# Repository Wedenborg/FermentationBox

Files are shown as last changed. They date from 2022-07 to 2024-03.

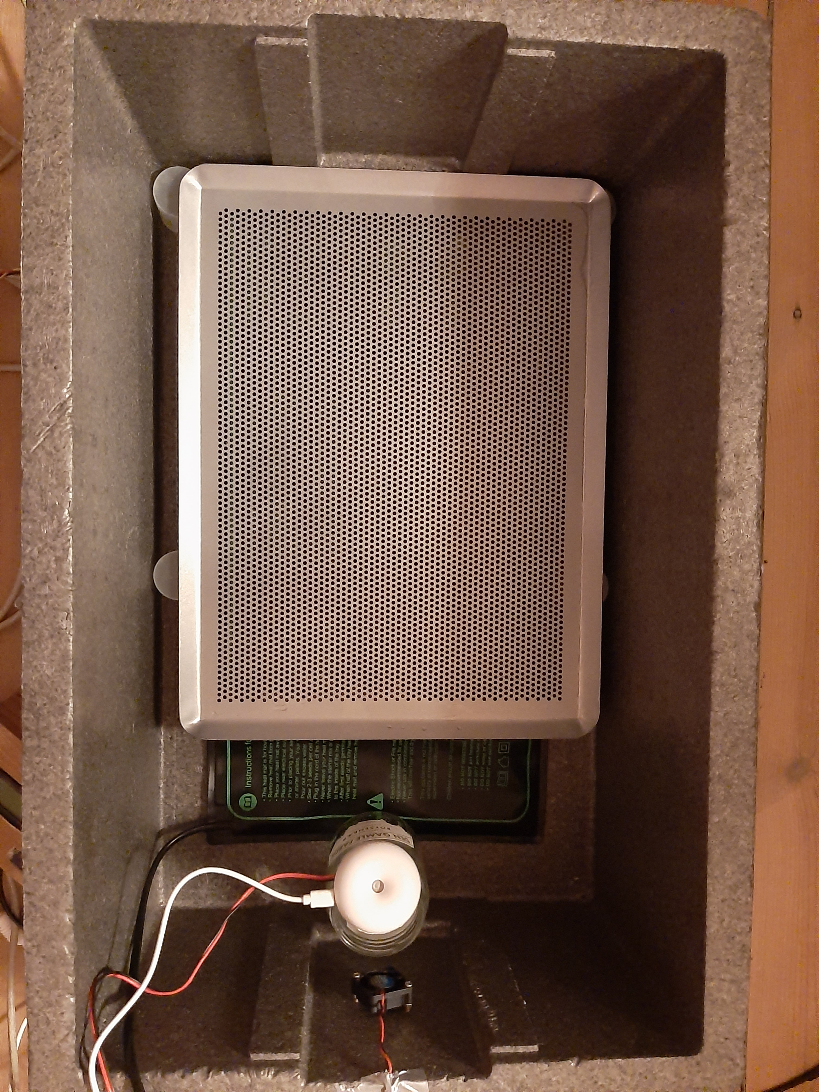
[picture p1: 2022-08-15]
photos/20220815_225923.jpg

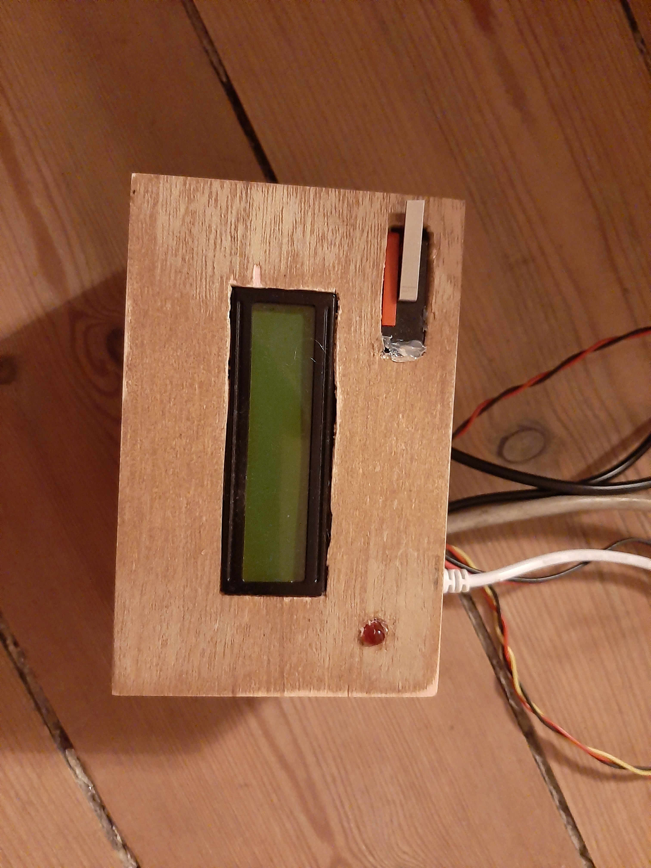
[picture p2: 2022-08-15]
photos/20220815_230012.jpg

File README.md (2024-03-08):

# Fermentation Box
Fermentation box inspired by Noma Guide to Fermentation. 

### Materials:

* 1 insulated box (approx. 60x39x24 cm)
* 1 Raspberry pi 3b+ 
* 1 Raspberry pi power supply
* 1 DHT11 sensor 
* 1 4 relay module (2PH63083A)
* 1 Heating mat 
* 1 Humidifier
* 1 LCD display
* 2 fans, one for the fermentation box and one for cooling hardware box
* 1 USB B to USB micro cable (approx. 2m)
* Wires 
* perforated baking tray (approx. 40x30 cm)
* 4 stands to lift the baking tray off the heating mat

### To be implemented: 

* More efficient control system -> It would be cool with a kalmanfilter or something! 

### Known issues that I do not know how to solve: 
* The humidifier turns on and off with a pulse signal. Sometimes something failes during start up, such that the humidifier is out of sync. \n I think I should replace the humidifier with one that has a real on/off switch and not just a pulse. 

### Modify rc.local to run on start up: 

1. On the Pi edit the rc.local file, which can be accessed using the following command: 

``` sudo nano /etc/rc.local ```

2. Add the file to be executed at the bottom of the page, but before the ```exit 0``` command. Here & is added at the end of the filename, as the script runs continously. 

```python3 /home/pi/FermentationBox/main.py &```

3. Make sure file is executeable. 

```sudo chmod +x /etc/rc.local```

4. Reboot system. 

```sudo reboot```

Now the program should start. 

### Setup:
fritzing file also available. 
Be aware of the gpio pins. The numbering varies between the code and the fritzing sketch.

![alt text](https://github.com/Wedenborg/FermentationBox/blob/main/preliminaryTestSetup.png)

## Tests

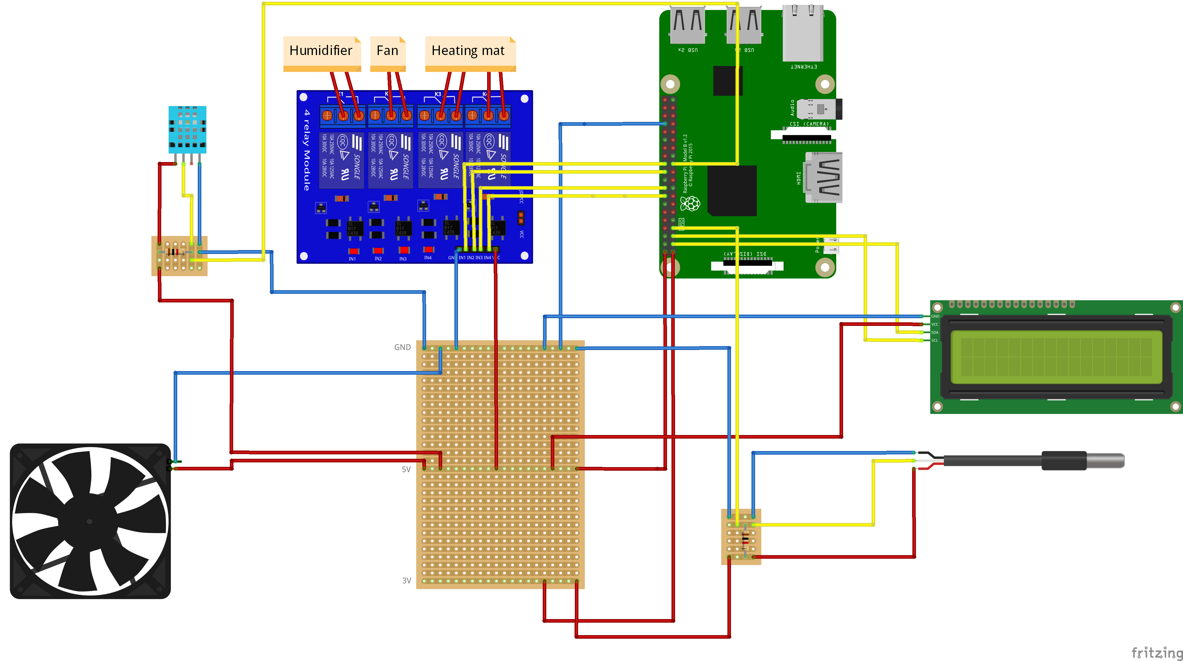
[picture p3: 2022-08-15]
preliminaryTestSetup.png

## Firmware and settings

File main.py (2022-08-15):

import os
import glob
import numpy as np
import Adafruit_DHT
import RPi.GPIO as GPIO
from datetime import datetime
# Import sleep Module for timing
from time import sleep
import csv

import i2c_lcd_driver 
import temperature_sensor_code as stickTemp

import mysql.connector as msql
from mysql.connector import Error

os.system('modprobe w1-gpio')
os.system('modprobe w1-therm')
base_dir = '/sys/bus/w1/devices/'
device_folder = glob.glob(base_dir + '28*')[0]
device_file = device_folder + '/w1_slave'


# Define pins
BlaaTemp = 22 
BrunTemp = 23
Sensor = 25
Humid = 27
Fan = 24
knap = 5
led = 6

mylcd = i2c_lcd_driver.lcd()
GPIO.setmode(GPIO.BCM)
GPIO.setwarnings(False)
GPIO.setup(BlaaTemp, GPIO.OUT) # GPIO Assign mode
GPIO.setup(BrunTemp, GPIO.OUT) # GPIO Assign mode
GPIO.setup(Humid, GPIO.OUT) # GPIO Assign mode
GPIO.setup(Sensor, GPIO.OUT) # GPIO Assign mode
GPIO.setup(Fan, GPIO.OUT) # GPIO Assign mode
GPIO.setup(led, GPIO.OUT) # GPIO Assign mode
GPIO.setup(knap, GPIO.IN) # GPIO Assign mode


 
def heatmatON(temp1,temp2):
    # Function that turns on heating mat
    GPIO.output(temp1, GPIO.LOW)
    GPIO.output(temp2, GPIO.LOW)

    return

def heatmatOFF(temp1,temp2):
    # Function that turns off heating mat
    GPIO.output(temp1, GPIO.HIGH)
    GPIO.output(temp2, GPIO.HIGH)

    return

def signalHumidifier(Humid):
    # Function that turns the humidifier on or off
    GPIO.output(Humid, GPIO.LOW)
    sleep(1)
    GPIO.output(Humid, GPIO.HIGH)
    return

def writeToDB(path,p):
    dbData =open(path,'r+')
    conn = msql.connect(host=p[0], user=p[1],  
            password=p[2]) #give ur username, password
    try:
        for row in dbData:
            t = row.strip('\n').split(',')
            cursor = conn.cursor()
            cursor.execute("use bnew_dk_db;")
            sql = 'INSERT INTO bnew_dk_db.kojiTable VALUES (%s,%s,%s,%s,%s);'
            cursor.execute(sql,t)
            # the connection is not auto committed by default, so we must commit to save our changes
            conn.commit()
    except Error as e:
        mylcd.lcd_display_string("Error while connecting to MySQL",1)
        mylcd.lcd_display_string(e,2)
    else:
        fileVariable = open(path, 'r+')
        temp = fileVariable.truncate(0)
        fileVariable.close()
    finally:
        dbData.close()
    return
    

def storeData(tempS, temperature, humidity, path):
    line = str(tempS) + "," + str(temperature) + "," + str(humidity) + "," + datetime.now().strftime('%Y-%m-%d %H:%M:%S') + "," + str(humidifier)
    out=open(path,"a")
    t = out.write(line+'\n')
    out.close()
    return

p = np.loadtxt("/home/emilie/Desktop/Code/FermentationBox/db.txt", delimiter=",", dtype=str)
path = '/home/emilie/Desktop/Code/FermentationBox/test.txt'


time = datetime.now()
timeOld = time
lastStored = time
humidifier = 0
GPIO.output(Fan, GPIO.LOW) # Turn on fan for better air circulation
heatmatOFF(BlaaTemp,BrunTemp)
mylcd.lcd_display_string("Starting...",1,0)
KorHumid = 1
f = 20
GPIO.output(led,GPIO.LOW) 
while True:
    time = datetime.now()
    
    knapInd = GPIO.input(knap)
    if (knapInd == 1):
        if (KorHumid == 1):
            KorHumid = 0
            GPIO.output(led,GPIO.HIGH)
            if (humidifier == 1):
                humidifier = 0
                signalHumidifier(Humid)
            sleep(3)
        else:
            KorHumid = 1
            GPIO.output(led,GPIO.LOW)
    
        
    tempS = stickTemp.read_temp()
    humidity, temperature = Adafruit_DHT.read_retry(11, Sensor)
    if humidity is not None and temperature is not None:
        mylcd.lcd_clear()
        mylcd.lcd_display_string("Temperature: "+str(tempS),1,0)
        mylcd.lcd_display_string("Humidity: "+str(humidity),2,0)
        mylcd.lcd_display_string(str(knapInd),2,15)

    if abs((time-lastStored).total_seconds()) >= 60:
        storeData(tempS, temperature, humidity,path)
        lastStored = datetime.now()
            
            
    if tempS < 28:
        heatmatON(BlaaTemp,BrunTemp)
    elif tempS > 34:
        heatmatOFF(BlaaTemp,BrunTemp)
            
            
    if humidity < 70 and KorHumid == 1 and humidifier == 0:
        if abs((time-timeOld).total_seconds()) >= 120:
            signalHumidifier(Humid)
            humidifier = 1
            timeOld = time

            if humidity <60:
                f = 40
            else: 
                f = 20

    if KorHumid == 1 and humidifier == 1 and abs((time-timeOld).total_seconds()) >= f:
        signalHumidifier(Humid)
        humidifier = 0
        timeOld = time

    if datetime.now().strftime('%H:%M') == '00:00':
        writeToDB(path,p)

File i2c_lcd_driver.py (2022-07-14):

# -*- coding: utf-8 -*-
# Original code found at:
# https://gist.github.com/DenisFromHR/cc863375a6e19dce359d

"""
Compiled, mashed and generally mutilated 2014-2015 by Denis Pleic
Made available under GNU GENERAL PUBLIC LICENSE

# Modified Python I2C library for Raspberry Pi
# as found on http://www.recantha.co.uk/blog/?p=4849
# Joined existing 'i2c_lib.py' and 'lcddriver.py' into a single library
# added bits and pieces from various sources
# By DenisFromHR (Denis Pleic)
# 2015-02-10, ver 0.1

"""

# i2c bus (0 -- original Pi, 1 -- Rev 2 Pi)
I2CBUS = 1

# LCD Address
ADDRESS = 0x27

import smbus
from time import sleep

class i2c_device:
   def __init__(self, addr, port=I2CBUS):
      self.addr = addr
      self.bus = smbus.SMBus(port)

# Write a single command
   def write_cmd(self, cmd):
      self.bus.write_byte(self.addr, cmd)
      sleep(0.0001)

# Write a command and argument
   def write_cmd_arg(self, cmd, data):
      self.bus.write_byte_data(self.addr, cmd, data)
      sleep(0.0001)

# Write a block of data
   def write_block_data(self, cmd, data):
      self.bus.write_block_data(self.addr, cmd, data)
      sleep(0.0001)

# Read a single byte
   def read(self):
      return self.bus.read_byte(self.addr)

# Read
   def read_data(self, cmd):
      return self.bus.read_byte_data(self.addr, cmd)

# Read a block of data
   def read_block_data(self, cmd):
      return self.bus.read_block_data(self.addr, cmd)


# commands
LCD_CLEARDISPLAY = 0x01
LCD_RETURNHOME = 0x02
LCD_ENTRYMODESET = 0x04
LCD_DISPLAYCONTROL = 0x08
LCD_CURSORSHIFT = 0x10
LCD_FUNCTIONSET = 0x20
LCD_SETCGRAMADDR = 0x40
LCD_SETDDRAMADDR = 0x80

# flags for display entry mode
LCD_ENTRYRIGHT = 0x00
LCD_ENTRYLEFT = 0x02
LCD_ENTRYSHIFTINCREMENT = 0x01
LCD_ENTRYSHIFTDECREMENT = 0x00

# flags for display on/off control
LCD_DISPLAYON = 0x04
LCD_DISPLAYOFF = 0x00
LCD_CURSORON = 0x02
LCD_CURSOROFF = 0x00
LCD_BLINKON = 0x01
LCD_BLINKOFF = 0x00

# flags for display/cursor shift
LCD_DISPLAYMOVE = 0x08
LCD_CURSORMOVE = 0x00
LCD_MOVERIGHT = 0x04
LCD_MOVELEFT = 0x00

# flags for function set
LCD_8BITMODE = 0x10
LCD_4BITMODE = 0x00
LCD_2LINE = 0x08
LCD_1LINE = 0x00
LCD_5x10DOTS = 0x04
LCD_5x8DOTS = 0x00

# flags for backlight control
LCD_BACKLIGHT = 0x08
LCD_NOBACKLIGHT = 0x00

En = 0b00000100 # Enable bit
Rw = 0b00000010 # Read/Write bit
Rs = 0b00000001 # Register select bit

class lcd:
   #initializes objects and lcd
   def __init__(self):
      self.lcd_device = i2c_device(ADDRESS)

      self.lcd_write(0x03)
      self.lcd_write(0x03)
      self.lcd_write(0x03)
      self.lcd_write(0x02)

      self.lcd_write(LCD_FUNCTIONSET | LCD_2LINE | LCD_5x8DOTS | LCD_4BITMODE)
      self.lcd_write(LCD_DISPLAYCONTROL | LCD_DISPLAYON)
      self.lcd_write(LCD_CLEARDISPLAY)
      self.lcd_write(LCD_ENTRYMODESET | LCD_ENTRYLEFT)
      sleep(0.2)


   # clocks EN to latch command
   def lcd_strobe(self, data):
      self.lcd_device.write_cmd(data | En | LCD_BACKLIGHT)
      sleep(.0005)
      self.lcd_device.write_cmd(((data & ~En) | LCD_BACKLIGHT))
      sleep(.0001)

   def lcd_write_four_bits(self, data):
      self.lcd_device.write_cmd(data | LCD_BACKLIGHT)
      self.lcd_strobe(data)

   # write a command to lcd
   def lcd_write(self, cmd, mode=0):
      self.lcd_write_four_bits(mode | (cmd & 0xF0))
      self.lcd_write_four_bits(mode | ((cmd << 4) & 0xF0))

   # write a character to lcd (or character rom) 0x09: backlight | RS=DR<
   # works!
   def lcd_write_char(self, charvalue, mode=1):
      self.lcd_write_four_bits(mode | (charvalue & 0xF0))
      self.lcd_write_four_bits(mode | ((charvalue << 4) & 0xF0))
  
   # put string function with optional char positioning
   def lcd_display_string(self, string, line=1, pos=0):
    if line == 1:
      pos_new = pos
    elif line == 2:
      pos_new = 0x40 + pos
    elif line == 3:
      pos_new = 0x14 + pos
    elif line == 4:
      pos_new = 0x54 + pos

    self.lcd_write(0x80 + pos_new)

    for char in string:
      self.lcd_write(ord(char), Rs)

   # clear lcd and set to home
   def lcd_clear(self):
      self.lcd_write(LCD_CLEARDISPLAY)
      self.lcd_write(LCD_RETURNHOME)

   # define backlight on/off (lcd.backlight(1); off= lcd.backlight(0)
   def backlight(self, state): # for state, 1 = on, 0 = off
      if state == 1:
         self.lcd_device.write_cmd(LCD_BACKLIGHT)
      elif state == 0:
         self.lcd_device.write_cmd(LCD_NOBACKLIGHT)

   # add custom characters (0 - 7)
   def lcd_load_custom_chars(self, fontdata):
      self.lcd_write(0x40);
      for char in fontdata:
         for line in char:
            self.lcd_write_char(line)      

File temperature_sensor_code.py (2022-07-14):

"""
Code from https://github.com/pimylifeup/temperature_sensor/blob/master/temperature_sensor_code.py
"""

import os
import glob
import time
 
os.system('modprobe w1-gpio')
os.system('modprobe w1-therm')
 
base_dir = '/sys/bus/w1/devices/'
device_folder = glob.glob(base_dir + '28*')[0]
device_file = device_folder + '/w1_slave'
 
def read_temp_raw():
    f = open(device_file, 'r')
    lines = f.readlines()
    f.close()
    return lines
 
def read_temp():
    lines = read_temp_raw()
    while lines[0].strip()[-3:] != 'YES':
        time.sleep(0.2)
        lines = read_temp_raw()
    equals_pos = lines[1].find('t=')
    if equals_pos != -1:
        temp_string = lines[1][equals_pos+2:]
        temp_c = float(temp_string) / 1000.0
        return temp_c
	

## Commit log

2022-06-14 [Script up and running]
    [test.csv]
2022-06-14 [Updates to readme and added except keyboard interrupt to main]
2022-06-15 [Error corrected in humidifier function]
    [main.py]
2022-07-14 [system extended with fan, LCD display and temperature probe]
    [test.csv]
2022-07-14 [code w. ref for display and probe]
    [test.csv]
2022-07-14 [problems with display on start up]
    [test.csv]
2022-07-16 [Program edited to use current time instead of sleep]
    [test.csv]
2022-08-15 New fritzing sketch
    [testSetup.fzz]
